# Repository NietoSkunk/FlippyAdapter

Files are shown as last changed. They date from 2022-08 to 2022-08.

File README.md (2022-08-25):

# FlippyAdapter

IDE Ribbon Cable Adapter for the [Luminator MAX3000](https://github.com/NietoSkunk/FlippyDriver) Flip Dot Panel.

This exists to solve an issue with the FlippyDriver, namely that the driver is physically attached to the board and extends outside the footprint of the panel. 

It supports both 34- and 40-pin IDE ribbon cables, or any form of 0.1" IDC connector.

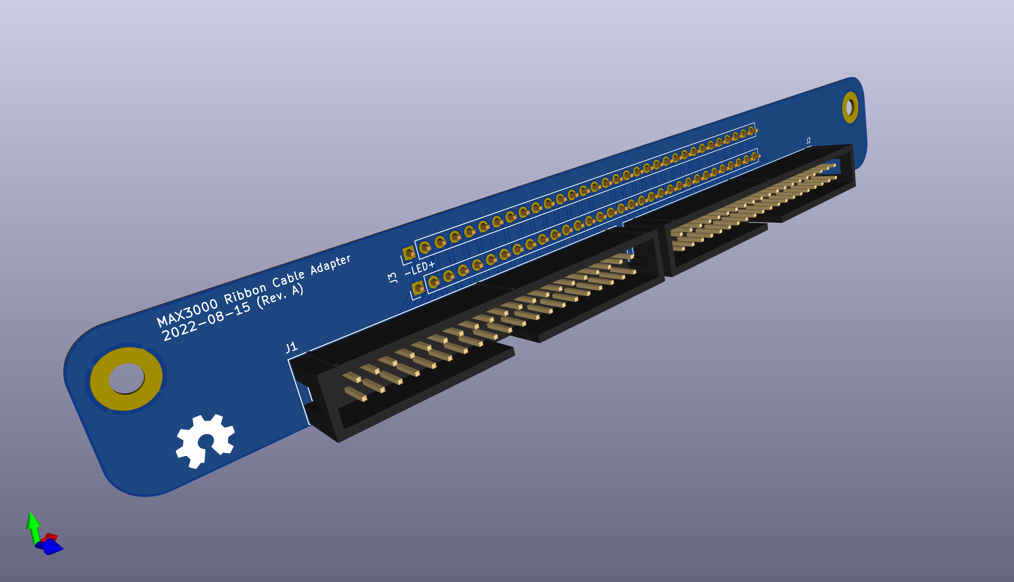
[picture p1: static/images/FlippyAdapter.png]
board render


## Cloning repository (with Submodules)

```bash
$ git clone --recurse-submodules git@github.com:NietoSkunk/FlippyAdapter.git
```

## Production notes

* When populating 34-pin IDC connector headers, the connectors should be in the center of the board, such that there are six pins on the outside edges of each connector. 
* The headers may be populated upside down to mechanically fit, although care should be taken to ensure the wiring does not get reversed at the other end of the ribbon cable.
* The two screw holes are M3 sized, and fit a 10mm M3 header to the holes in the board.

## Board Harness

| Pin | # | # | Pin |
| --- | - | - | --- |
| LED- | 1 | 2 | LED- |
| LED+ | 3 | 4 | LED+ |
| ROW_2_RESET | 5 | 6 | ROW_2_SET |
| ROW_4_RESET | 7 | 8 | ROW_4_SET |
| ROW_6_RESET | 9 | 10 | ROW_6_SET |
| ROW_8_RESET | 11 | 12 | ROW_8_SET |
| ROW_10_RESET | 13 | 14 | ROW_10_SET |
| ROW_12_RESET | 15 | 16 | ROW_12_SET |
| ROW_14_RESET | 17 | 18 | ROW_14_SET |
| ROW_16_RESET | 19 | 20 | ROW_16_SET |
| ROW_15_RESET | 21 | 22 | ROW_15_SET |
| ROW_13_RESET | 23 | 24 | ROW_13_SET |
| ROW_11_RESET | 25 | 26 | ROW_11_SET |
| ROW_9_RESET | 27 | 28 | ROW_9_SET |
| ROW_7_RESET | 29 | 30 | ROW_7_SET |
| ROW_5_RESET | 31 | 32 | ROW_5_SET |
| ROW_3_RESET | 33 | 34 | ROW_3_SET |
| ROW_1_RESET | 35 | 36 | ROW_1_SET |
| COL_2 | 37 | 38 | COL_1 |
| COL_4 | 39 | 40 | COL_3 |
| COL_6 | 41 | 42 | COL_5 |
| COL_8 | 43 | 44 | COL_7 |
| COL_10 | 45 | 46 | COL_9 |
| COL_12 | 47 | 48 | COL_11 |
| COL_14 | 49 | 50 | COL_13 |
| COL_16 | 51 | 52 | COL_15 |
| COL_18 | 53 | 54 | COL_17 |
| COL_20 | 55 | 56 | COL_19 |
| COL_22 | 57 | 58 | COL_21 |
| COL_24 | 59 | 60 | COL_23 |
| COL_26 | 61 | 62 | COL_25 |
| COL_28 | 63 | 64 | COL_27 |

## IDC Connectors

| Pin | # | # | Pin |
| --- | - | - | --- |
| N/C | 1 | 2 | N/C |
| N/C | 3 | 4 | N/C |
| N/C | 5 | 6 | N/C |
| LED- | 7 | 8 | LED- |
| LED- | 9 | 10 | LED- |
| LED+ | 11 | 12 | LED+ |
| LED+ | 13 | 14 | LED+ |
| ROW_2_RESET | 15 | 16 | ROW_2_SET |
| ROW_4_RESET | 17 | 18 | ROW_4_SET |
| ROW_6_RESET | 19 | 20 | ROW_6_SET |
| ROW_8_RESET | 21 | 22 | ROW_8_SET |
| ROW_10_RESET | 23 | 24 | ROW_10_SET |
| ROW_12_RESET | 25 | 26 | ROW_12_SET |
| ROW_14_RESET | 27 | 28 | ROW_14_SET |
| ROW_16_RESET | 29 | 30 | ROW_16_SET |
| ROW_15_RESET | 31 | 32 | ROW_15_SET |
| ROW_13_RESET | 33 | 34 | ROW_13_SET |
| ROW_11_RESET | 35 | 36 | ROW_11_SET |
| ROW_9_RESET | 37 | 38 | ROW_9_SET |
| ROW_7_RESET | 39 | 40 | ROW_7_SET |

| Pin | # | # | Pin |
| --- | - | - | --- |
| ROW_5_RESET | 1 | 2 | ROW_5_SET |
| ROW_3_RESET | 3 | 4 | ROW_3_SET |
| ROW_1_RESET | 5 | 6 | ROW_1_SET |
| COL_2 | 7 | 8 | COL_1 |
| COL_4 | 9 | 10 | COL_3 |
| COL_6 | 11 | 12 | COL_5 |
| COL_8 | 13 | 14 | COL_7 |
| COL_10 | 15 | 16 | COL_9 |
| COL_12 | 17 | 18 | COL_11 |
| COL_14 | 19 | 20 | COL_13 |
| COL_16 | 21 | 22 | COL_15 |
| COL_18 | 23 | 24 | COL_17 |
| COL_20 | 25 | 26 | COL_19 |
| COL_22 | 27 | 28 | COL_21 |
| COL_24 | 29 | 30 | COL_23 |
| COL_26 | 31 | 32 | COL_25 |
| COL_28 | 33 | 34 | COL_27 |
| N/C | 35 | 36 | N/C |
| N/C | 37 | 38 | N/C |
| N/C | 39 | 40 | N/C |

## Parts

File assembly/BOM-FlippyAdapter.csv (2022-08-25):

Comment | Designator | Footprint | LCSC
MountingHole_Pad | H1 | MountingHole_3.5mm_Pad_TopBottom
MountingHole_Pad | H2 | MountingHole_3.5mm_Pad_TopBottom
Board Harness | J3 | Luminator_MAX3000
Conn_02x20_Odd_Even | J1 | IDC-Header_2x20_P2.54mm_Vertical
Conn_02x20_Odd_Even | J2 | IDC-Header_2x20_P2.54mm_Vertical

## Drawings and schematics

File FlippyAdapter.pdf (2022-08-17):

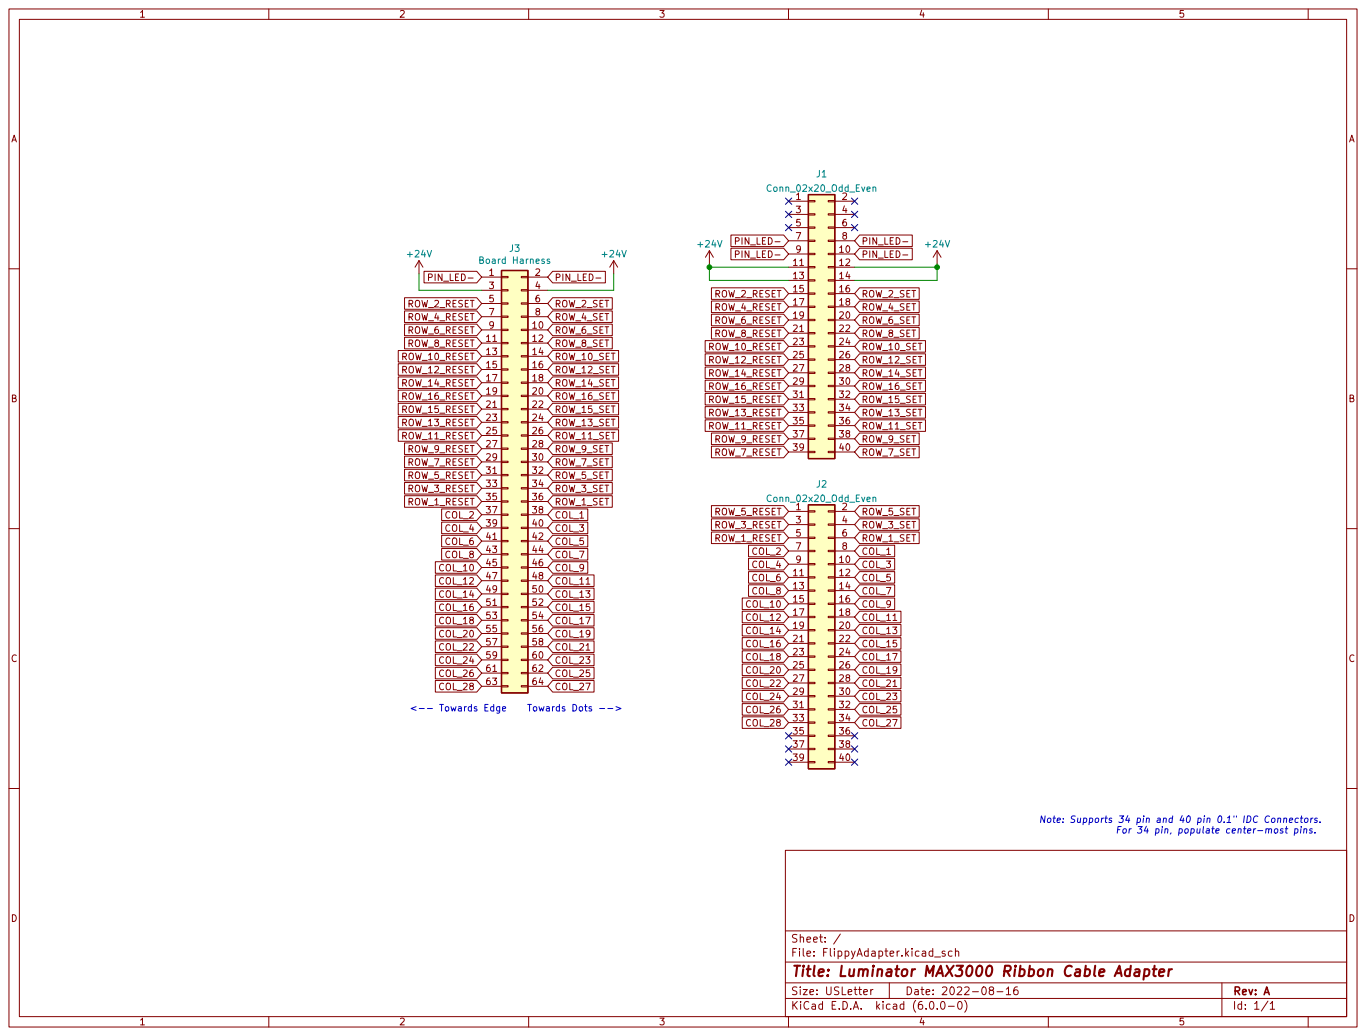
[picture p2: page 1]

<-- Towards Edge Towards Dots -->

For 34 pin, populate center-most pins.

File: FlippyAdapter.kicad_sch Sheet: /
Id: 1/1 Title: Luminator MAX3000 Ribbon Cable Adapter

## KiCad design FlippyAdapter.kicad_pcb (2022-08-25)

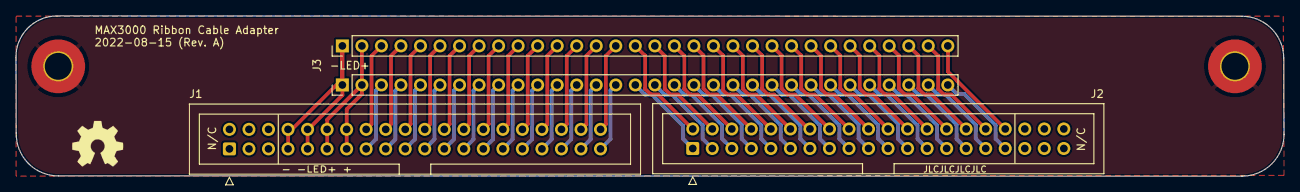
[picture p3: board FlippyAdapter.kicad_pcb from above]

Board: 2 copper layers, 164.9 x 20.8 mm, 6 parts (0 on the bottom side), 63 nets.

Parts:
H1, H2: MountingHole_Pad; MountingHole_3.5mm_Pad_TopBottom
J1, J2: Conn_02x20_Odd_Even; IDC-Header_2x20_P2.54mm_Vertical
J3: Board Harness; Luminator_MAX3000
JLCJLCJLCJLC: JLCJLCJLCJLC; JLCPCB_OrderNumber

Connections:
+24V: J1.11, J1.12, J1.13, J1.14, J3.3, J3.4
COL_1: J2.8, J3.38
COL_2: J2.7, J3.37
COL_3: J2.10, J3.40
COL_4: J2.9, J3.39
COL_5: J2.12, J3.42
COL_6: J2.11, J3.41
COL_7: J2.14, J3.44
COL_8: J2.13, J3.43
COL_9: J2.16, J3.46
COL_10: J2.15, J3.45
COL_11: J2.18, J3.48
COL_12: J2.17, J3.47
COL_13: J2.20, J3.50
COL_14: J2.19, J3.49
COL_15: J2.22, J3.52
COL_16: J2.21, J3.51
COL_17: J2.24, J3.54
COL_18: J2.23, J3.53
COL_19: J2.26, J3.56
COL_20: J2.25, J3.55
COL_21: J2.28, J3.58
COL_22: J2.27, J3.57
COL_23: J2.30, J3.60
COL_24: J2.29, J3.59
COL_25: J2.32, J3.62
COL_26: J2.31, J3.61
COL_27: J2.34, J3.64
COL_28: J2.33, J3.63
PIN_GND: H1.1, H2.1
PIN_LED-: J1.7, J1.8, J1.9, J1.10, J3.1, J3.2
ROW_1_RESET: J2.5, J3.35
ROW_1_SET: J2.6, J3.36
ROW_2_RESET: J1.15, J3.5
ROW_2_SET: J1.16, J3.6
ROW_3_RESET: J2.3, J3.33
ROW_3_SET: J2.4, J3.34
ROW_4_RESET: J1.17, J3.7
ROW_4_SET: J1.18, J3.8
ROW_5_RESET: J2.1, J3.31
ROW_5_SET: J2.2, J3.32
ROW_6_RESET: J1.19, J3.9
ROW_6_SET: J1.20, J3.10
ROW_7_RESET: J1.39, J3.29
ROW_7_SET: J1.40, J3.30
ROW_8_RESET: J1.21, J3.11
ROW_8_SET: J1.22, J3.12
ROW_9_RESET: J1.37, J3.27
ROW_9_SET: J1.38, J3.28
ROW_10_RESET: J1.23, J3.13
ROW_10_SET: J1.24, J3.14
ROW_11_RESET: J1.35, J3.25
ROW_11_SET: J1.36, J3.26
ROW_12_RESET: J1.25, J3.15
ROW_12_SET: J1.26, J3.16
ROW_13_RESET: J1.33, J3.23
ROW_13_SET: J1.34, J3.24
ROW_14_RESET: J1.27, J3.17
ROW_14_SET: J1.28, J3.18
ROW_15_RESET: J1.31, J3.21
ROW_15_SET: J1.32, J3.22
ROW_16_RESET: J1.29, J3.19
ROW_16_SET: J1.30, J3.20

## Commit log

2022-08-17 Initial Revision of Flippy Adapter
    [FlippyAdapter-CuBottom.gbr, FlippyAdapter-CuTop.gbr, FlippyAdapter-EdgeCuts.gbr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]
2022-08-25 Add libraries submodule
    [BOM-FlippyAdapter.csv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]
2022-08-25 Remove internal library
    [BOM-FlippyAdapter.csv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]
